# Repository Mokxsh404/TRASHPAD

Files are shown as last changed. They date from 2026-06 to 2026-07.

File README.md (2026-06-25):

# TRASHPAD ⌨️

a macropad i built because i was tired of reaching for shortcuts that don't exist. got out of hand. zero regrets.

## what is this

TRASHPAD is a custom programmable macropad — 9 keys, a rotary encoder, and a tiny OLED screen that actually tells you what's going on. built it for a hackathon and then kept going way past the point where "good enough" would've been fine. ended up with a full custom PCB, a 3D-printable case, and a website to go with it.

👉 **[try the interactive demo](https://mokxsh404.github.io/TRASHPAD/)**

## what's inside

🔘 **9 programmable keys** — fully remappable through a QMK firmware matrix. bind them to whatever you actually use, not whatever the factory default thinks you need.

🎛️ **EC11 rotary encoder** — volume, scrubbing, scrolling through a timeline, whatever. smooth, satisfying, and somehow the part everyone immediately gravitates to when they pick it up.

📟 **0.91" OLED display** — shows live layer state and active macros so you're not just guessing what your own keyboard is doing. small detail, makes the whole thing feel like a real device instead of a breadboard with delusions of grandeur.

🧠 **XIAO RP2040** — tiny controller, does all the heavy lifting, somehow still cheaper than a fancy keycap set.

## where it's at

PCB is designed, firmware is configured, and the production files (gerbers included) are ready to send to a fab. case is modeled and exported. basically: this thing exists in CAD and code, and the build/test phase is where it's at right now.

## the build

**schematic**
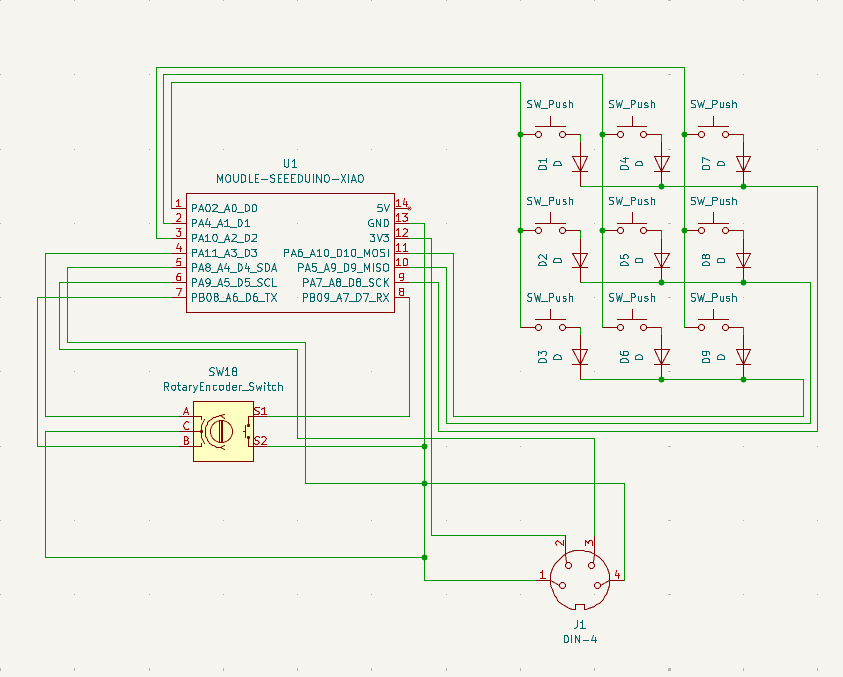
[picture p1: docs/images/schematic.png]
TRASHPAD schematic


**PCB**
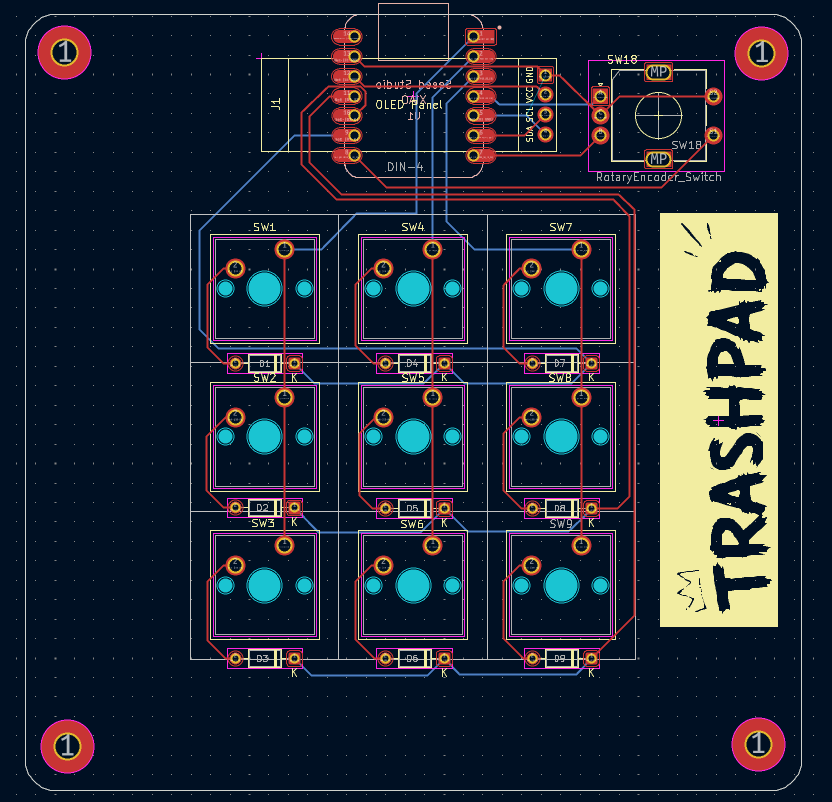
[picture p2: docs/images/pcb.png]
TRASHPAD PCB


**CAD model**
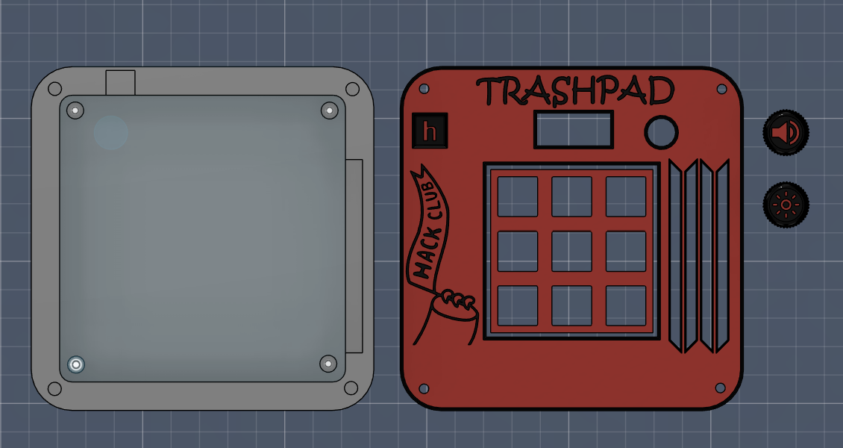
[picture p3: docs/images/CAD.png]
TRASHPAD CAD model


## bill of materials (bom)

Here is everything you need to source to build your own TRASHPAD. All parts are standard and easy to find on sites like AliExpress, Amazon, or specialized keyboard vendors.

| Component | Description | Qty | Est. Cost | Notes |
| :--- | :--- | :---: | :---: | :--- |
| **Seeed Studio XIAO RP2040** | Dual-core Cortex-M0+ microcontroller, USB-C | 1 | ~$5.50 | Main controller footprint |
| **0.91" I2C OLED Display** | SSD1306, 128x32 screen | 1 | ~$3.00 | 4-pin header connection |
| **EC11 Rotary Encoder** | EC11 encoder with push-button switch, D-shaft (15mm) | 1 | ~$1.50 | 5-pin footprint |
| **Keyswitches** | Cherry MX-compatible switches (Gateron, Kailh, etc.) | 9 | ~$4.00 | Soldered directly to PCB |
| **1u Keycaps** | MX-style keycaps | 9 | ~$3.00 | Standard 1u size |
| **1N4148 Diodes** | Switching diodes | 9 | ~$0.50 | SOD-123 surface mount |
| **TRASHPAD Custom PCB** | Custom printed circuit board (Fab & Shipping) | 1 | ~$6.00 | JLCPCB/PCBWay fab + shipping share |
| **3D Printed Case & Knob** | Top casing, bottom plate, and encoder knob | 1 | ~$5.00 | Using local hub / custom printing service |
| **M3 Threaded Inserts** | Brass heat-set inserts | 4 | ~$0.50 | Ø 4.7mm × 4.0mm inserts |
| **M3 Machine Screws** | M3 screws for case | 4 | ~$0.50 | M3 × 6mm or 8mm button-head |
| **Rubber Feet** | Self-adhesive silicone bumpers | 4 | ~$0.50 | Ø 8mm x 2mm feet |
| **Total Build Cost** | | | **~$30.00** | *(Excludes tools, shipping, USB-C)* |

## repo structure

- `CAD/` — full assembled model for reference (`assembled-model.step`)
- `docs/` — the interactive site/simulator, this is what's live on GitHub Pages
- `Frimware/` — QMK config: keymaps, `config.h`, `keyboard.json`, `rules.mk`
- `PCB/` — KiCad project, schematic, and PCB layout files
- `Production/` — fab-ready output: gerbers, case STEPs (`Top.step`, `Bottom.step`), and the `trashpad/` build folder

## stack

KiCad for the PCB, QMK for firmware, plain HTML/CSS/JS for the site — no frameworks, no build step, just files that work.

## resources that actually helped

- [ai03's PCB guide](https://wiki.ai03.com/) — if you've never routed a board before, start here
- [the keyboard designer wiki](https://wiki.keyboardatelier.com/)
- [Joe Scotto's case tutorials](https://www.youtube.com/watch?v=33mCOnFioY0)

## about

I wanted a macropad.

Instead of buying one, I spent days learning PCB design, designing a case in Fusion, configuring firmware, and making a website for it.

TRASHPAD is the result.

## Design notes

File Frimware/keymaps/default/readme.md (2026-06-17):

# trashpad

![trashpad]

A handbuilt 9-key macropad with a rotary encoder and 0.91" OLED display. Built around the Seeed XIAO RP2040.

* Keyboard Maintainer: [Moksha Kumbhaj](https://github.com/Mokxsh404)
* Hardware Supported: Custom PCB (XIAO RP2040), EC11 rotary encoder, 0.91" I2C OLED (SSD1306)
* Hardware Availability: coming soon

Make example for this keyboard (after setting up your build environment):

    make trashpad:default

Flashing example for this keyboard:

    make trashpad:default:flash

See the [build environment setup](https://docs.qmk.fm/#/getting_started_build_tools) and the [make instructions](https://docs.qmk.fm/#/getting_started_make_guide) for more information. Brand new to QMK? Start with our [Complete Newbs Guide](https://docs.qmk.fm/#/newbs).

## Bootloader

Enter the bootloader in 3 ways:

* **Bootmagic reset**: Hold down the key at (0,0) in the matrix (usually the top left key) and plug in the keyboard
* **Physical reset button**: Hold the BOOT button on the XIAO RP2040, then plug in via USB
* **Keycode in layout**: Press the key mapped to `QK_BOOT` if it is available

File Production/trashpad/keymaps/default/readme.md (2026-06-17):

# trashpad

trashpad

*A short description of the keyboard/project*

* Keyboard Maintainer: [Moksha Kumbhaj](https://github.com/Mokxsh404)
* Hardware Supported: *The PCBs, controllers supported*
* Hardware Availability: *Links to where you can find this hardware*

Make example for this keyboard (after setting up your build environment):

    make trashpad:default

Flashing example for this keyboard:

    make trashpad:default:flash

See the [build environment setup](https://docs.qmk.fm/#/getting_started_build_tools) and the [make instructions](https://docs.qmk.fm/#/getting_started_make_guide) for more information. Brand new to QMK? Start with our [Complete Newbs Guide](https://docs.qmk.fm/#/newbs).

## Bootloader

Enter the bootloader in 3 ways:

* **Bootmagic reset**: Hold down the key at (0,0) in the matrix (usually the top left key or Escape) and plug in the keyboard
* **Physical reset button**: Briefly press the button on the back of the PCB - some may have pads you must short instead
* **Keycode in layout**: Press the key mapped to `QK_BOOT` if it is available

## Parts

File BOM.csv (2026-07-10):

Component | Category | Description | Qty | Est. Price
Seeed Studio XIAO RP2040 | Logic | Dual-core Cortex-M0+ MCU, USB-C connector | 1 | $5.50
0.91" I2C OLED Display | Display | SSD1306, 128x32 pixels, 4-pin interface | 1 | $3.00
EC11 Rotary Encoder | Input | EC11 encoder with integrated push-switch, 15mm D-shaft | 1 | $1.50
Cherry MX-Compatible Switches | Input | MX switches of choice (Gateron, Kailh, Outemu, etc.) | 9 | $4.00
1u Keycaps | Input | MX-compatible 1u keycaps of choice | 9 | $3.00
1N4148 Diodes | Logic | Switching diodes (SOD-123 surface mount) | 9 | $0.50
TRASHPAD Custom PCB | PCB | Custom KiCad PCB (Fab & Shipping share) | 1 | $6.00
3D Printed Case & Knob | Case | Top shell, bottom plate, and knob (service/filament) | 1 | $5.00
M3 Threaded Inserts | Hardware | Brass heat-set inserts (Ø 4.7mm x 4.0mm) | 4 | $0.50
M3 Machine Screws | Hardware | M3 x 6mm or 8mm button head screws | 4 | $0.50
Rubber Feet | Hardware | Self-adhesive silicone bumper pads | 4 | $0.50
Estimated Build Total |  |  | 36 | ~$30.00

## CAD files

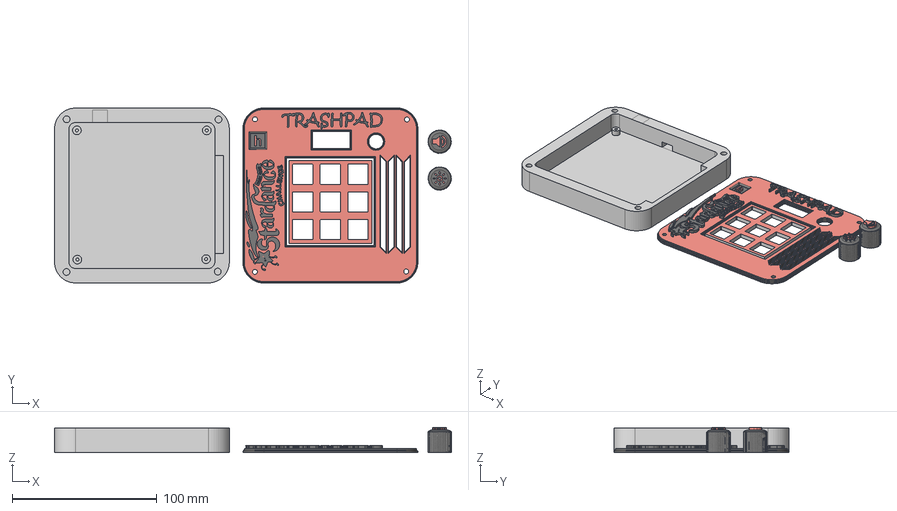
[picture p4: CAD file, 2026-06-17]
CAD/assembled-model.step
273.9 x 120.8 x 17.5 mm

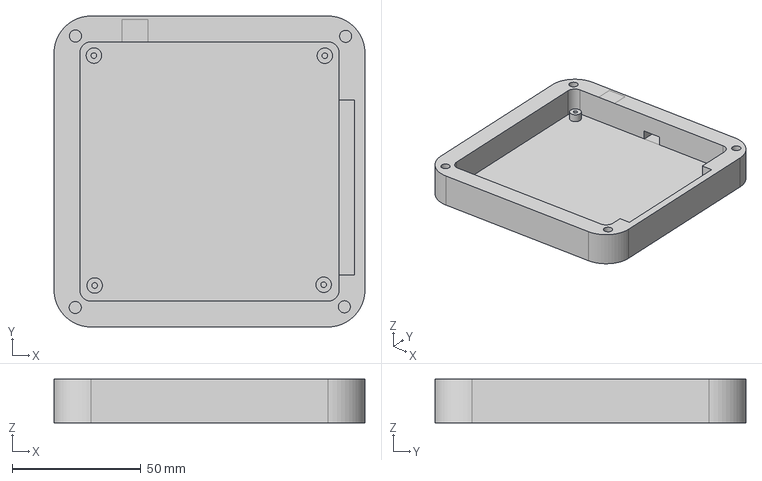
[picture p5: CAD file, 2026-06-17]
Production/Bottom.step
120.6 x 120.6 x 17.0 mm

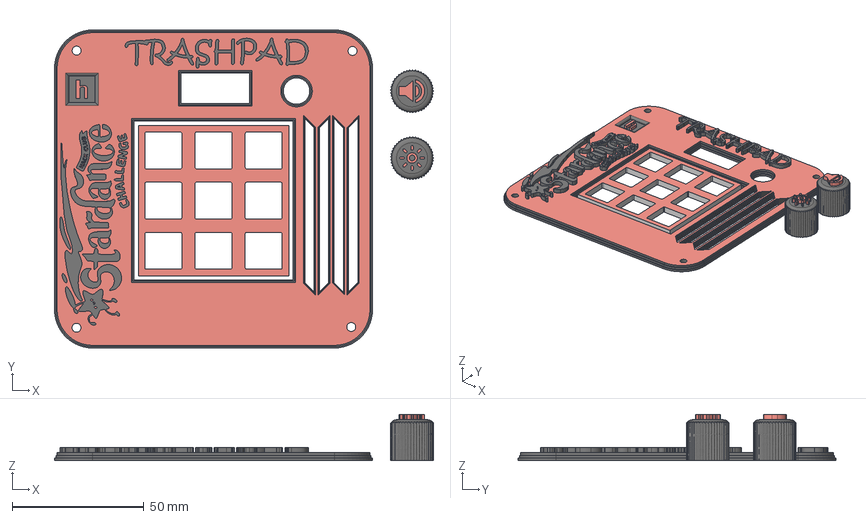
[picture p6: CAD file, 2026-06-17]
Production/Top.step
144.0 x 120.8 x 17.5 mm

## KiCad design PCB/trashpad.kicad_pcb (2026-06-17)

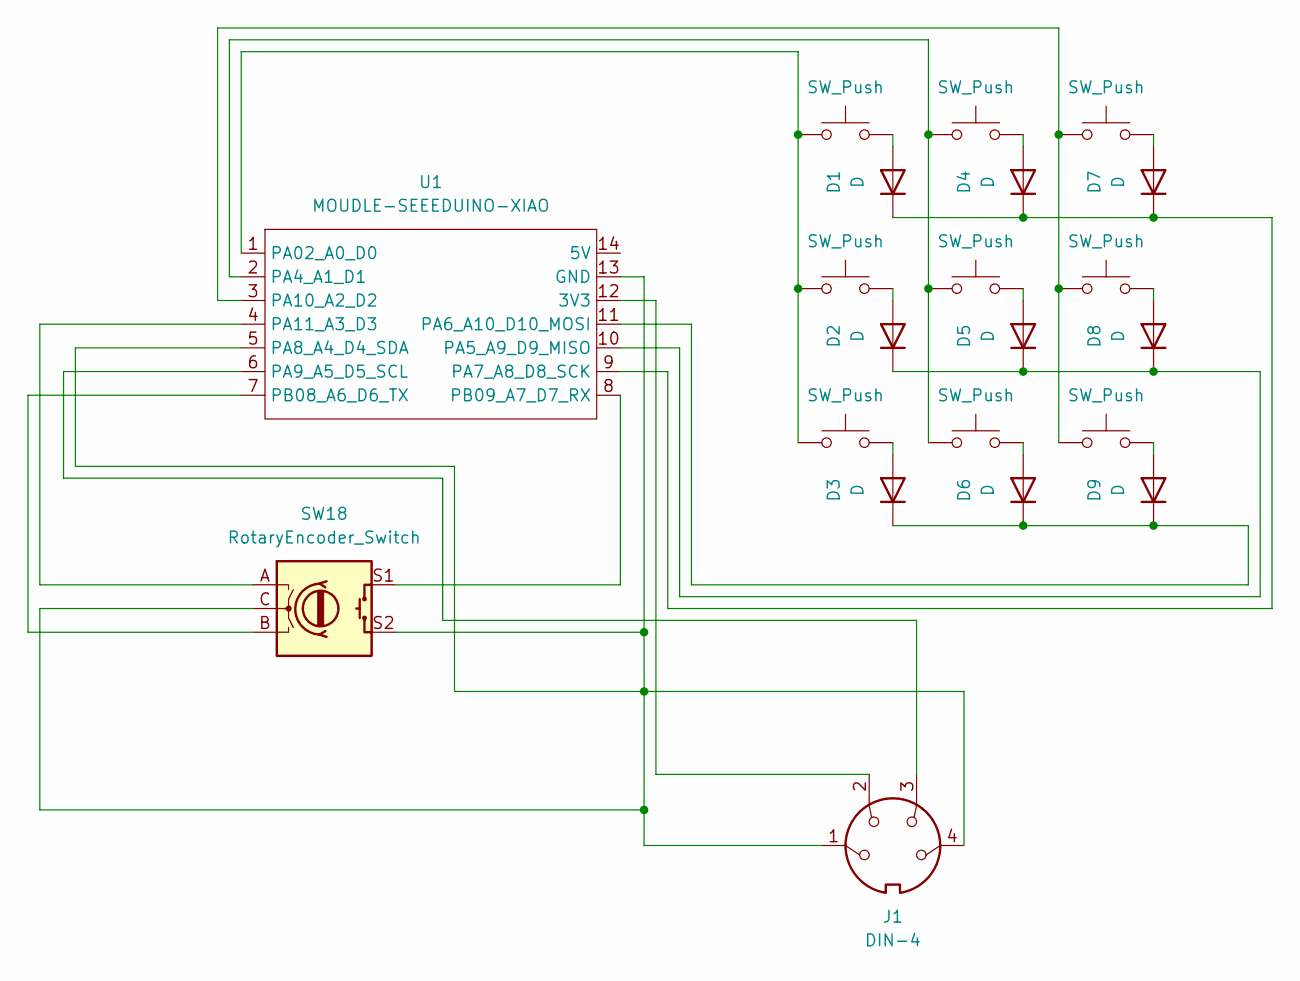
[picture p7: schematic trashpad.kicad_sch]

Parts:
D1, D2, D3, D4, D5, D6, D7, D8, D9: D; D_DO-35_SOD27_P7.62mm_Horizontal
J1: DIN-4; SSD1306-0.91-OLED-4pin-128x32
SW1, SW2, SW3, SW4, SW5, SW6, SW7, SW8, SW9: SW_Push; SW_Cherry_MX_1.00u_PCB
SW18: RotaryEncoder_Switch; RotaryEncoder_Alps_EC11E-Switch_Vertical_H20mm
U1: MOUDLE-SEEEDUINO-XIAO; XIAO-Generic-Hybrid-14P-2.54-21X17.8MM

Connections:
unnamed: D1.2 (A), SW1.2
unnamed: D1.1 (K), D4.1 (K), D7.1 (K), U1.9 (PA7_A8_D8_SCK)
unnamed: D2.2 (A), SW2.2
unnamed: D2.1 (K), D5.1 (K), D8.1 (K), U1.10 (PA5_A9_D9_MISO)
unnamed: D3.2 (A), SW3.2
unnamed: D3.1 (K), D6.1 (K), D9.1 (K), U1.11 (PA6_A10_D10_MOSI)
unnamed: D4.2 (A), SW4.2
unnamed: D5.2 (A), SW5.2
unnamed: D6.2 (A), SW6.2
unnamed: D7.2 (A), SW7.2
unnamed: D8.2 (A), SW8.2
unnamed: D9.2 (A), SW9.2
unnamed: J1.2, U1.12 (3V3)
unnamed: J1.1, J1.4, SW18.C, SW18.S2, U1.5 (PA8_A4_D4_SDA), U1.13 (GND)
unnamed: SW1.1, SW2.1, SW3.1, U1.1 (PA02_A0_D0)
unnamed: SW4.1, SW5.1, SW6.1, U1.2 (PA4_A1_D1)
unnamed: J1.3, U1.6 (PA9_A5_D5_SCL)
unnamed: SW7.1, SW8.1, SW9.1, U1.3 (PA10_A2_D2)
unnamed: SW18.A, U1.4 (PA11_A3_D3)
unnamed: SW18.B, U1.7 (PB08_A6_D6_TX)
unnamed: SW18.S1, U1.8 (PB09_A7_D7_RX)

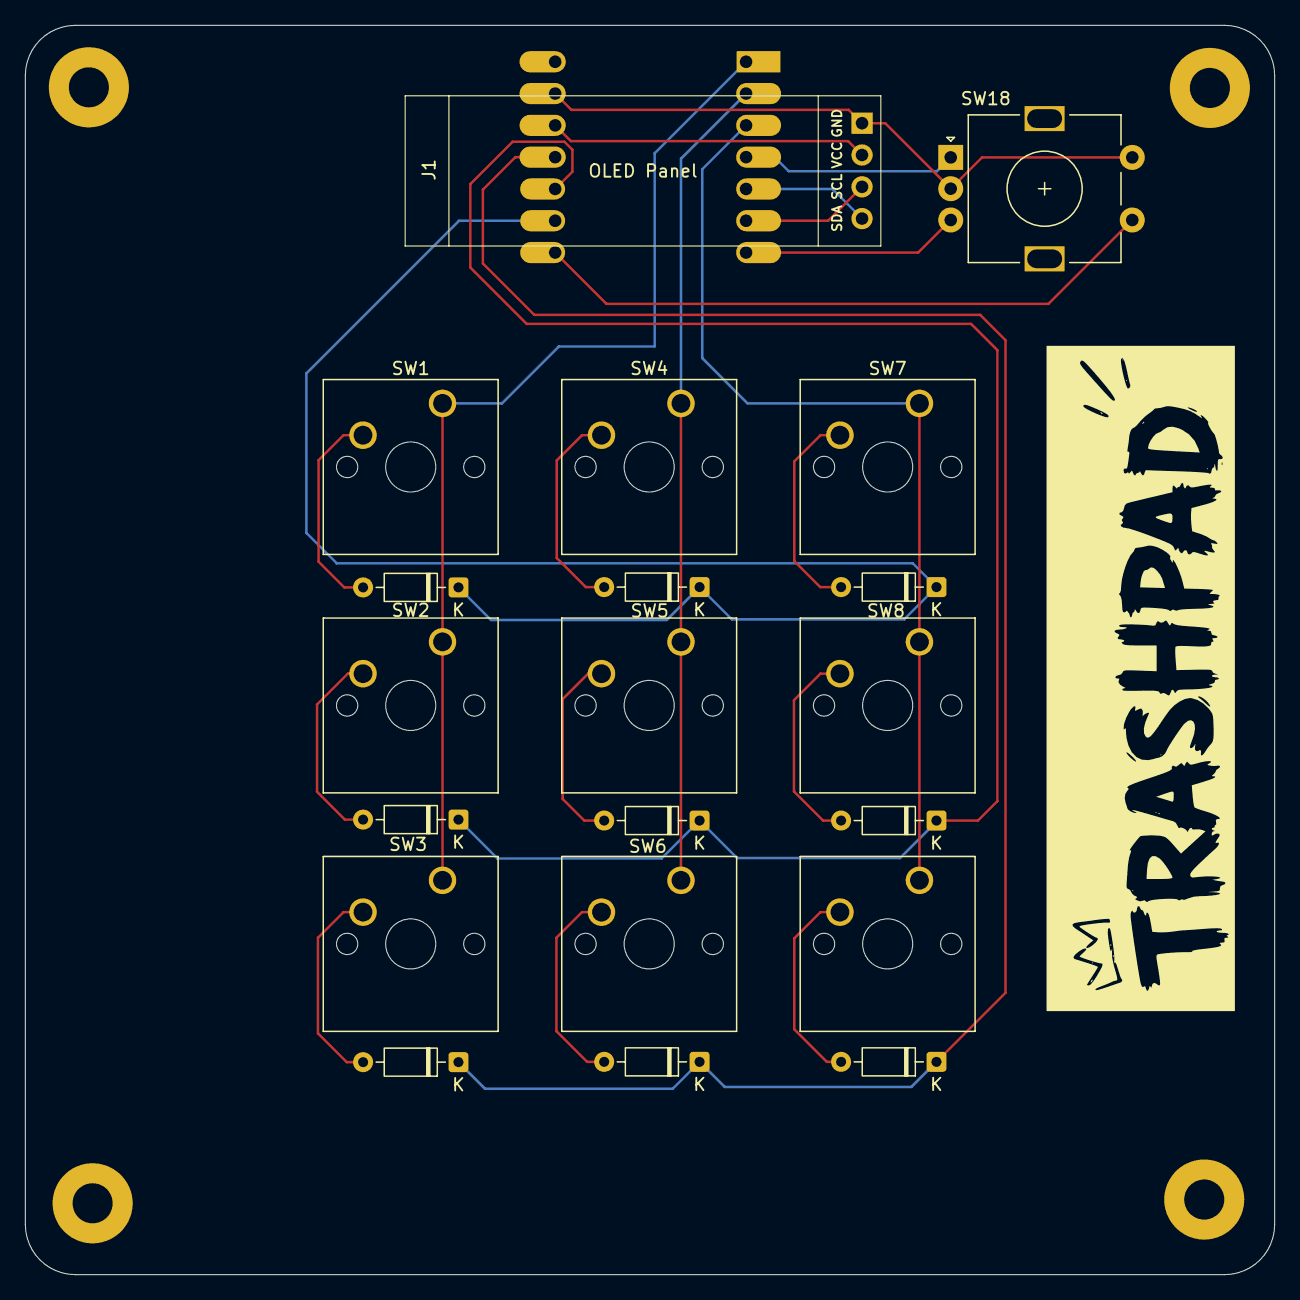
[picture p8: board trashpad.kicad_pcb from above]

Board: 2 copper layers, 99.8 x 99.8 mm, 21 parts (1 on the bottom side), 21 nets.

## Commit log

2026-06-24 Update CAD files and 3D model assets
2026-06-25 bom edit
2026-07-10 Added BOM.csv
    [BOM.csv]
2026-07-10 Convert BOM to CSV format with categories
    Updated BOM format from Markdown to CSV with additional categories.
    [BOM.csv]
